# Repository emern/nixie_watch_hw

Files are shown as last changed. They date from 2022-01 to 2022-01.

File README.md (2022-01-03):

# nixie_watch_hw
Hardware for an IN-16 nixie tube based wristwatch/pocketwatch designed in KiCAD 5.1.3. This project contains PCB for both the watch main-board and Nixie tube holder designed to be mounted perpendicularly to allow the tubes to be visible from above. Watch main-board contains both STM8L based MCU alongside 9v-186v flyback boost converter to supply the large running voltages required by the nixie tubes. More information on the IN-16 nixie tube can be found [here](http://www.tube-tester.com/sites/nixie/data/in16.htm).

## PCBs

There are two induvidual PCBs needed to construct this wristwatch.

* Watch main-board (MCU, power supply, nixie GPIO driver, status LED, input switches)
* Nixie tube holder (Nixie tube socket x2)

## Features

Some features of this watch include:

* 9v battery based power supply
* 9v-186v nixie tube power supply based on flyback boost topology
* Wake button, slider switch to select between various sleep modes
* Status (mins/hours mode) LED indicator
* 2 nixie tube display
* 32mm radius
* [Firmware avaliable](https://github.com/emern/nixie_watch_fw)

## License

This project is licensed under the GPL-3.0 License.

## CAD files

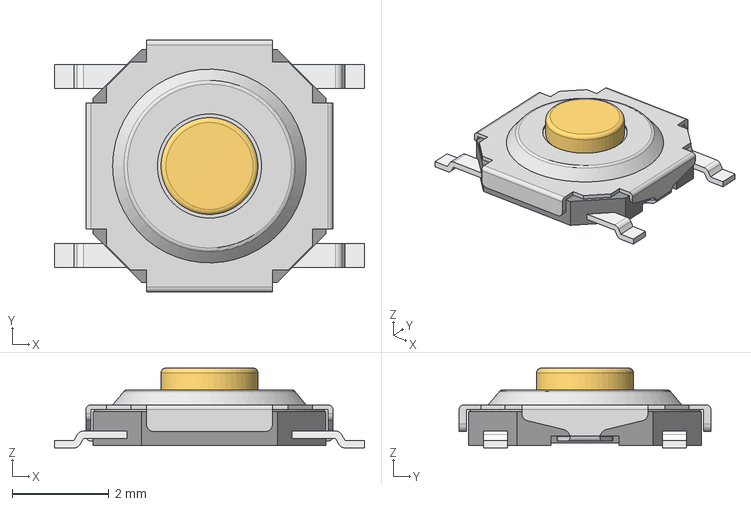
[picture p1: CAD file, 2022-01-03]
watch_v1/Switch_C&K_PTS526SK15SMTR2LFS/eec.models/C&K_-_PTS526SK15SMTR2LFS.step
6.40 x 5.20 x 1.65 mm

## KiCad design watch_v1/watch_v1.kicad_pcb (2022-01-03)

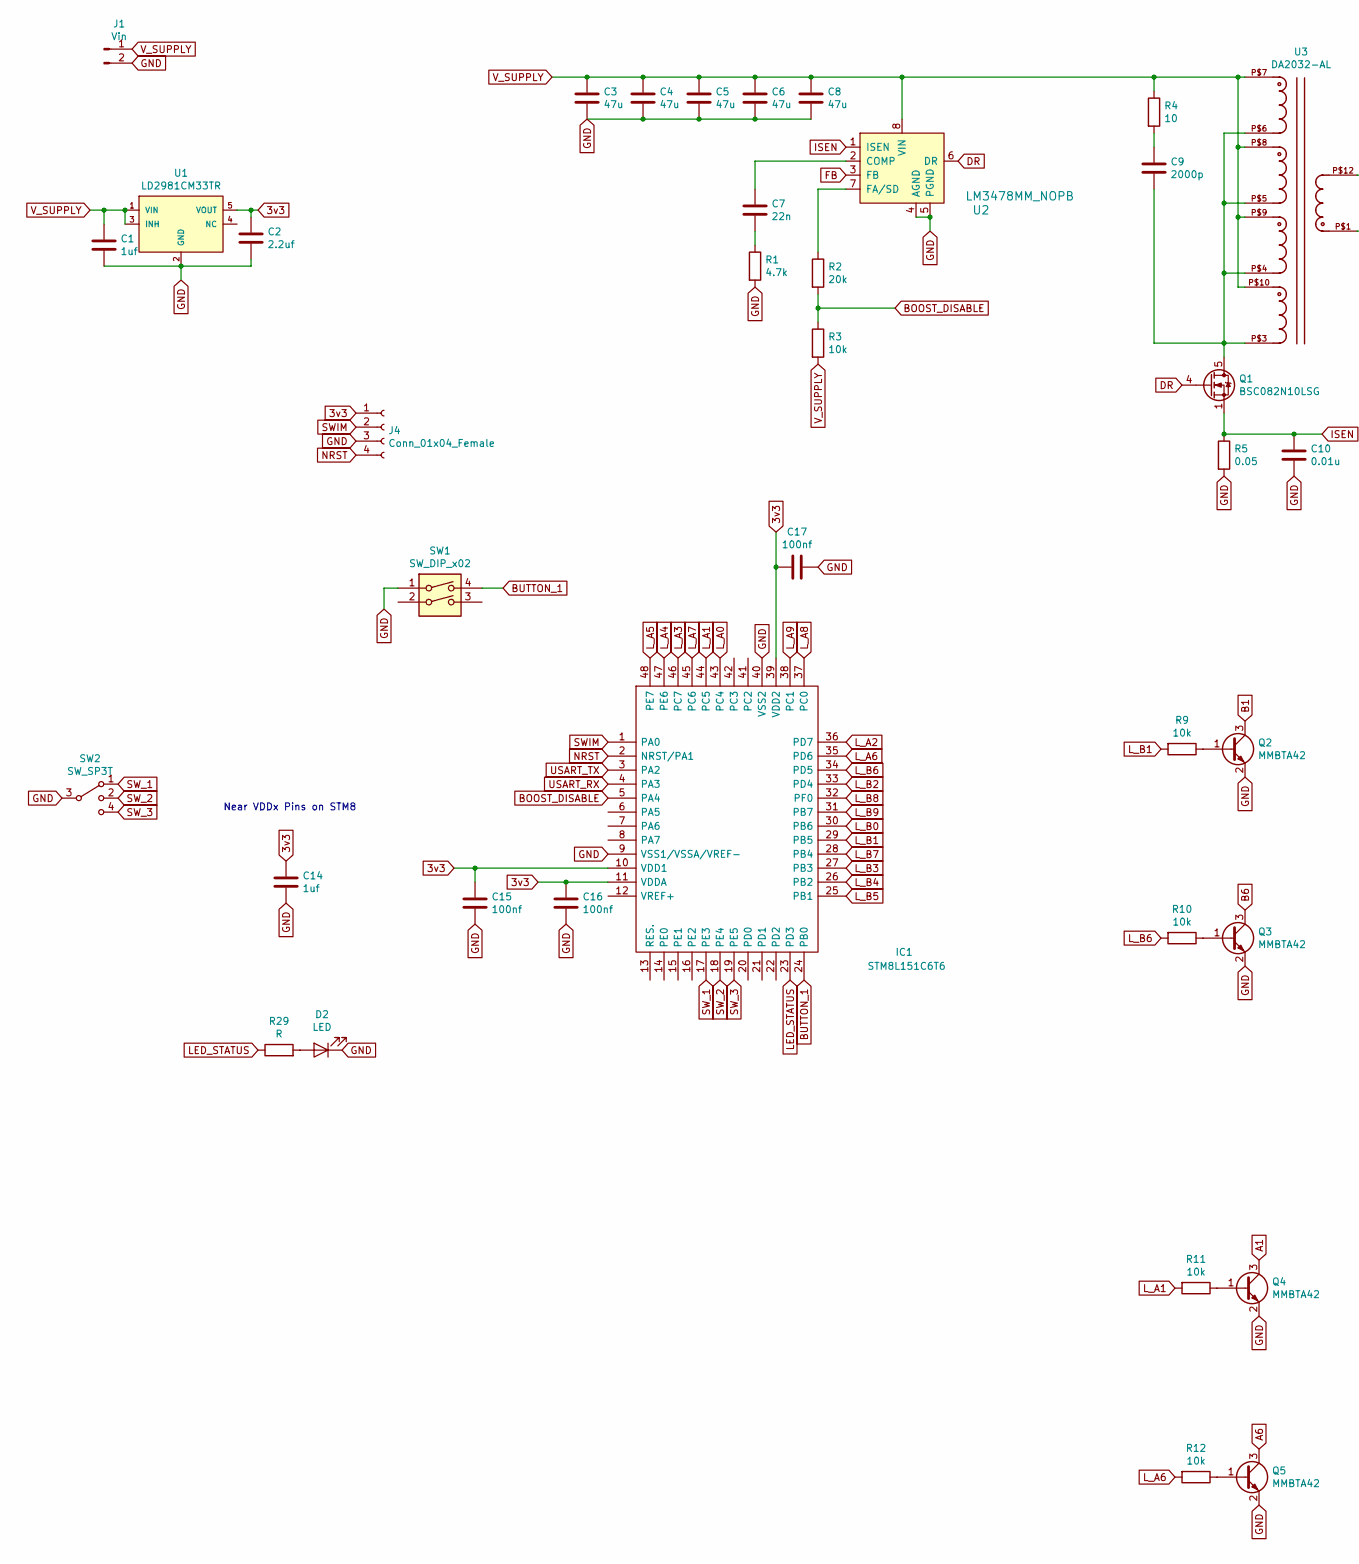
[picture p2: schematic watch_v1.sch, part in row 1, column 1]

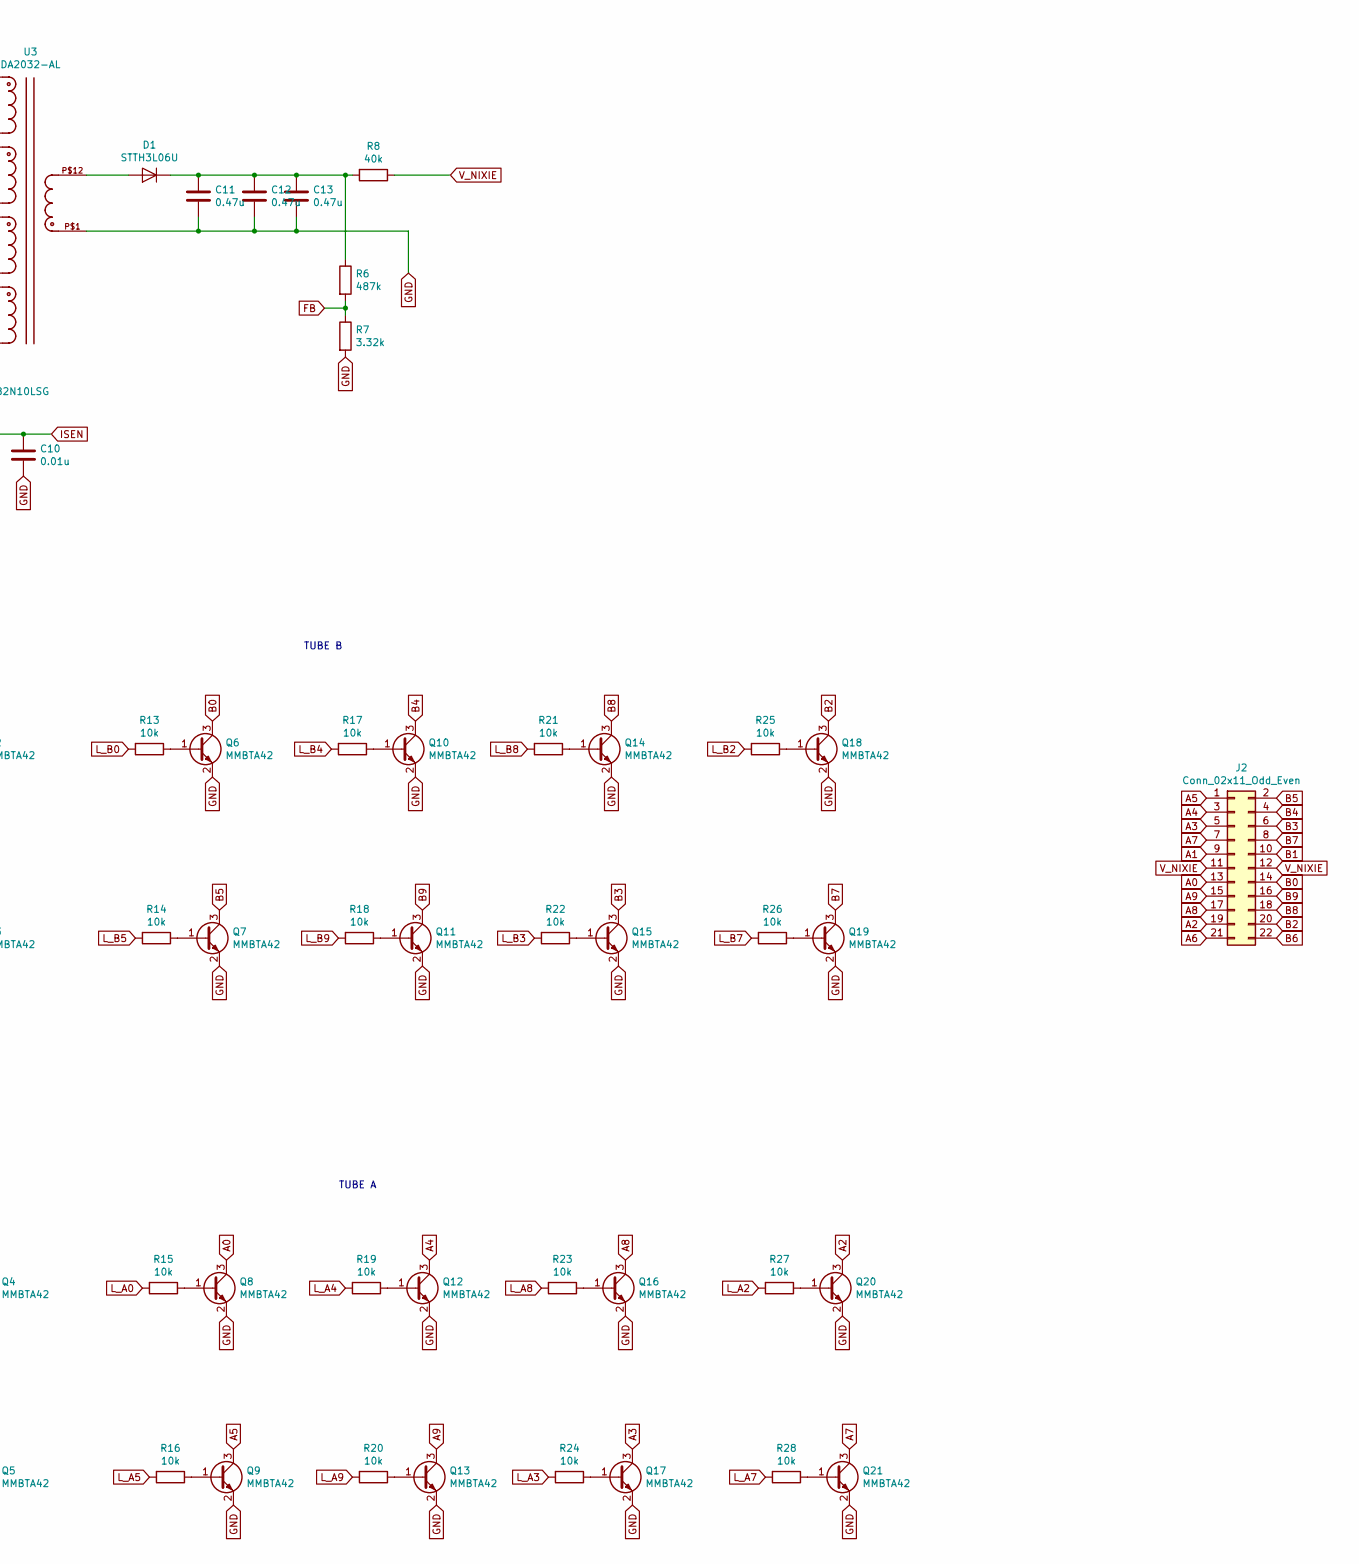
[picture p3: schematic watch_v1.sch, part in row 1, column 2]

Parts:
C1, C14: 1uf; C_1206_3216Metric
C2: 2.2uf; C_0805_2012Metric
C3, C4, C5, C6, C8: 47u; C_0805_2012Metric
C7: 22n; C_0402_1005Metric
C9: 2000p; C_0603_1608Metric
C10: 0.01u; C_0603_1608Metric
C11, C12, C13: 0.47u; C_1210_3225Metric
C15, C16, C17: 100nf; C_0805_2012Metric
D1: STTH3L06U; D_SMB
D2: LED; LED_0402_1005Metric
IC1: STM8L151C6T6; LQFP-48_7x7mm_P0.5mm; Manufacturer_Part_Number STM8L151C6T6; Mouser Part Number 511-STM8L151C6T6
J1: Vin; PinSocket_1x02_P2.54mm_Vertical
J2: Conn_02x11_Odd_Even; PinHeader_Nixie_1_37mm
J4: Conn_01x04_Female; PinHeader_1x04_P2.54mm_Vertical
Q1: BSC082N10LSG; TDSON-8-1
Q2, Q3, Q4, Q5, Q6, Q7, Q8, Q9, Q10, Q11, Q12, Q13, Q14, Q15, Q16, Q17, Q18, Q19, Q20, Q21: MMBTA42; SOT-23
R1: 4.7k; R_0805_2012Metric
R2: 20k; R_0603_1608Metric
R3: 10k; R_0603_1608Metric
R4: 10; R_0805_2012Metric
R5: 0.05; R_0402_1005Metric
R6: 487k; R_0805_2012Metric
R7: 3.32k; R_0603_1608Metric
R8: 40k; R_1206_3216Metric
R9, R10, R11, R12, R13, R14, R15, R16, R17, R18, R19, R20, R21, R22, R23, R24, R25, R26, R27, R28: 10k; R_0402_1005Metric
R29: R; R_1206_3216Metric
SW1: SW_DIP_x02; CK-PTS526SK15SMTR2LFS-0-0-MFG
SW2: SW_SP3T; SW_PCM13SMTR
U1: LD2981CM33TR; SOT-23-5
U2: LM3478MM_NOPB; SOIC-8_W3.9mm; MPN LM3478MM/NOPB; Digi-Key_PN LM3478MM/NOPBCT-ND
U3: DA2032-AL

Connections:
3v3: C2.1, C14.1, C15.1, C16.1, C17.2, IC1.10 (VDD1), IC1.11 (VDDA), IC1.39 (VDD2), J4.1, U1.5 (VOUT)
A0: J2.13, Q8.3 (C)
A1: J2.9, Q4.3 (C)
A2: J2.19, Q20.3 (C)
A3: J2.5, Q17.3 (C)
A4: J2.3, Q12.3 (C)
A5: J2.1, Q9.3 (C)
A6: J2.21, Q5.3 (C)
A7: J2.7, Q21.3 (C)
A8: J2.17, Q16.3 (C)
A9: J2.15, Q13.3 (C)
B0: J2.14, Q6.3 (C)
B1: J2.10, Q2.3 (C)
B2: J2.20, Q18.3 (C)
B3: J2.6, Q15.3 (C)
B4: J2.4, Q10.3 (C)
B5: J2.2, Q7.3 (C)
B6: J2.22, Q3.3 (C)
B7: J2.8, Q19.3 (C)
B8: J2.18, Q14.3 (C)
B9: J2.16, Q11.3 (C)
BOOST_DISABLE: IC1.5 (PA4), R2.2, R3.1
BUTTON_1: IC1.24 (PB0), SW1.4
DR: Q1.4 (G), U2.6 (DR)
FB: R6.2, R7.1, U2.3 (FB)
GND: C1.2, C2.2, C3.2, C4.2, C5.2, C6.2, C8.2, C10.2, C11.2, C12.2, C13.2, C14.2, C15.2, C16.2, C17.1, D2.1 (K), IC1.9 (VSS1/VSSA/VREF-), IC1.40 (VSS2), J1.2, J4.3, Q2.2 (E), Q3.2 (E), Q4.2 (E), Q5.2 (E), Q6.2 (E), Q7.2 (E), Q8.2 (E), Q9.2 (E), Q10.2 (E), Q11.2 (E), Q12.2 (E), Q13.2 (E), Q14.2 (E), Q15.2 (E), Q16.2 (E), Q17.2 (E), Q18.2 (E), Q19.2 (E), Q20.2 (E), Q21.2 (E), R1.2, R5.2, R7.2, SW1.1, SW2.3, U1.2 (GND), U2.4 (AGND), U2.5 (PGND), U3.P$1
ISEN: C10.1, Q1.1 (S), Q1.2 (S), Q1.3 (S), R5.1, U2.1 (ISEN)
LED_STATUS: IC1.23 (PD3), R29.1
L_A0: IC1.43 (PC4), R15.2
L_A1: IC1.44 (PC5), R11.2
L_A2: IC1.36 (PD7), R27.2
L_A3: IC1.46 (PC7), R24.2
L_A4: IC1.47 (PE6), R19.2
L_A5: IC1.48 (PE7), R16.2
L_A6: IC1.35 (PD6), R12.2
L_A7: IC1.45 (PC6), R28.2
L_A8: IC1.37 (PC0), R23.2
L_A9: IC1.38 (PC1), R20.2
L_B0: IC1.30 (PB6), R13.2
L_B1: IC1.29 (PB5), R9.2
L_B2: IC1.33 (PD4), R25.2
L_B3: IC1.27 (PB3), R22.2
L_B4: IC1.26 (PB2), R17.2
L_B5: IC1.25 (PB1), R14.2
L_B6: IC1.34 (PD5), R10.2
L_B7: IC1.28 (PB4), R26.2
L_B8: IC1.32 (PF0), R21.2
L_B9: IC1.31 (PB7), R18.2
NRST: IC1.2 (NRST/PA1), J4.4
unnamed: C7.1, U2.2 (COMP)
unnamed: C7.2, R1.1
unnamed: C9.1, R4.2
unnamed: C9.2, Q1.5 (D), U3.P$3, U3.P$4, U3.P$5, U3.P$6
unnamed: C11.1, C12.1, C13.1, D1.1 (K), R6.1, R8.2
unnamed: D1.2 (A), U3.P$12
unnamed: D2.2 (A), R29.2
unnamed: Q2.1 (B), R9.1
unnamed: Q3.1 (B), R10.1
unnamed: Q4.1 (B), R11.1
unnamed: Q5.1 (B), R12.1
unnamed: Q6.1 (B), R13.1
unnamed: Q7.1 (B), R14.1
unnamed: Q8.1 (B), R15.1
unnamed: Q9.1 (B), R16.1
unnamed: Q10.1 (B), R17.1
unnamed: Q11.1 (B), R18.1
unnamed: Q12.1 (B), R19.1
unnamed: Q13.1 (B), R20.1
unnamed: Q14.1 (B), R21.1
unnamed: Q15.1 (B), R22.1
unnamed: Q16.1 (B), R23.1
unnamed: Q17.1 (B), R24.1
unnamed: Q18.1 (B), R25.1
unnamed: Q19.1 (B), R26.1
unnamed: Q20.1 (B), R27.1
unnamed: Q21.1 (B), R28.1
unnamed: R2.1, U2.7 (FA/SD)
SWIM: IC1.1 (PA0), J4.2
SW_1: IC1.17 (PE3), SW2.1
SW_2: IC1.18 (PE4), SW2.2
SW_3: IC1.19 (PE5), SW2.4
USART_RX: IC1.4 (PA3)
USART_TX: IC1.3 (PA2)
V_NIXIE: J2.11, J2.12, R8.1
V_SUPPLY: C1.1, C3.1, C4.1, C5.1, C6.1, C8.1, J1.1, R3.2, R4.1, U1.1 (VIN), U1.3 (INH), U2.8 (VIN), U3.P$7, U3.P$8, U3.P$9, U3.P$10

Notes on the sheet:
Near VDDx Pins on STM8
TUBE B
TUBE A

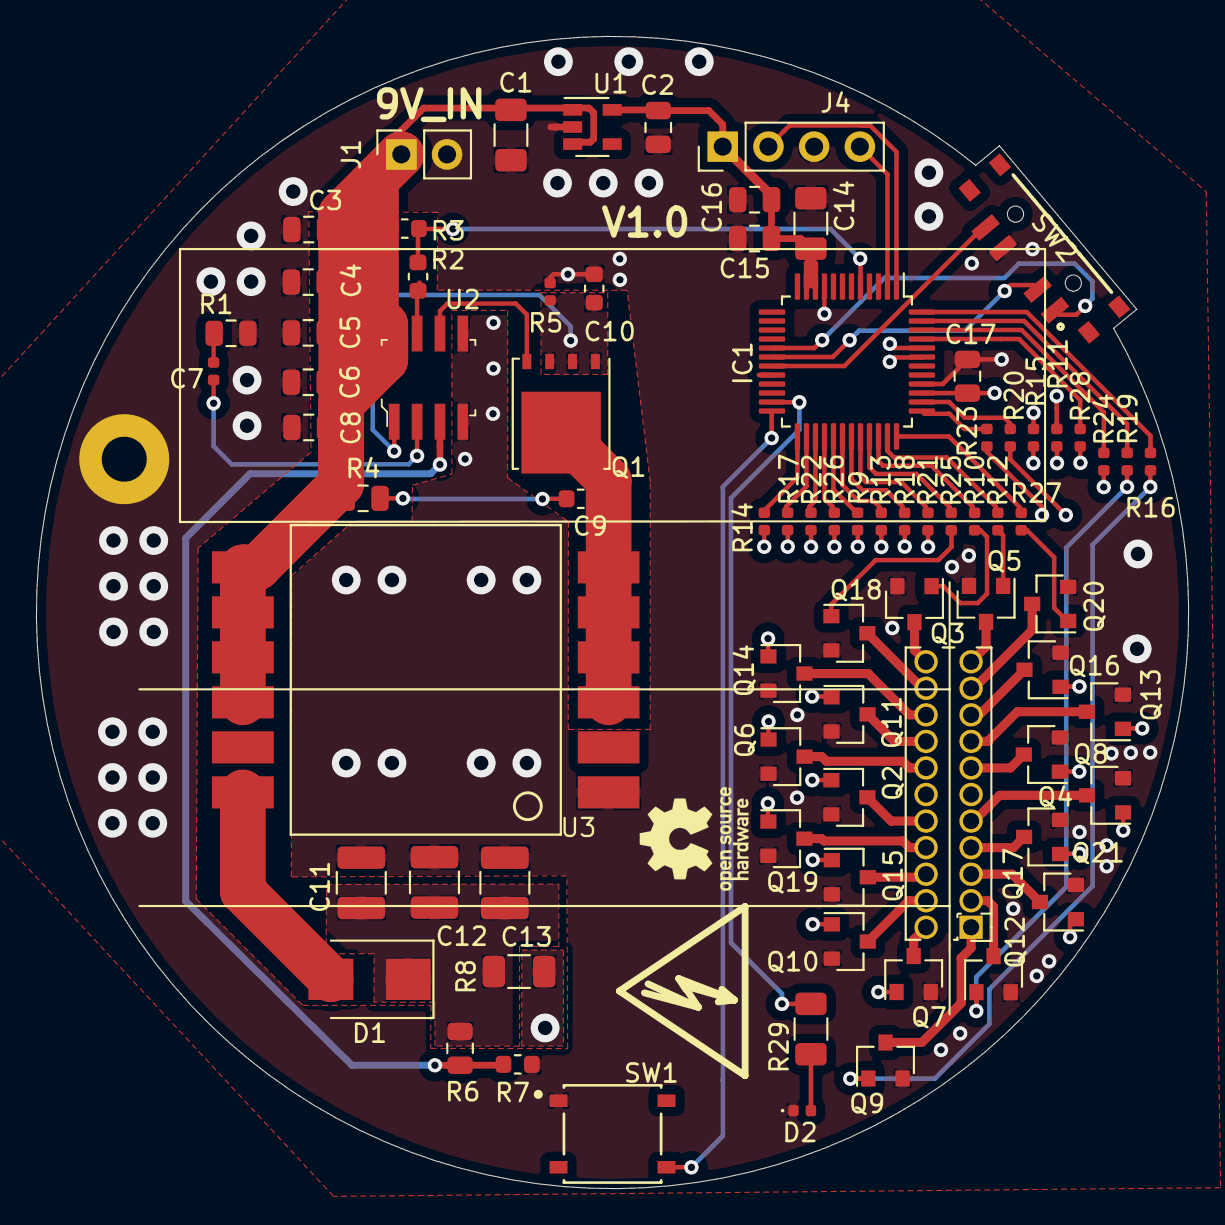
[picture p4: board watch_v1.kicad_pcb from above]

Board: 4 copper layers, 64.0 x 64.0 mm, 78 parts (0 on the bottom side), 83 nets.

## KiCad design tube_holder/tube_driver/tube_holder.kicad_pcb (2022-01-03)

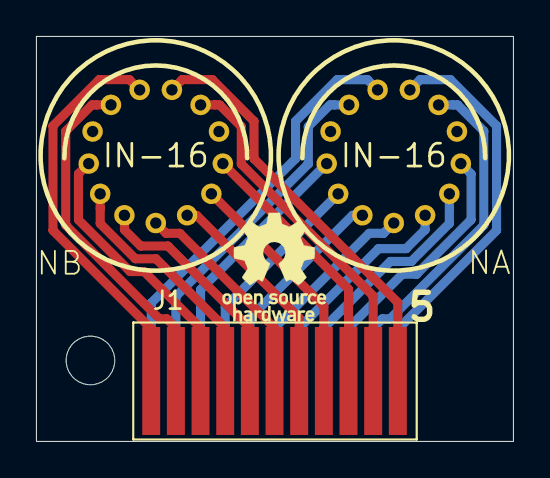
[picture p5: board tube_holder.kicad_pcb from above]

Board: 2 copper layers, 26.5 x 22.5 mm, 4 parts (1 on the bottom side), 22 nets.

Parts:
J1, J2: Conn_01x11_Female; smd_nixie_header_socket
NA: IN-16; nixies-us-IN-16
NB: IN-16; nixies-us-IN-16

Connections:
A0: J2.5, NA.0
A1: J2.7, NA.1
A2: J2.2, NA.2
A3: J2.9, NA.3
A4: J2.10, NA.4
A5: J2.11, NA.5
A6: J2.1, NA.6
A7: J2.8, NA.7
A8: J2.3, NA.8
A9: J2.4, NA.9
B0: J1.5, NB.0
B1: J1.7, NB.1
B2: J1.2, NB.2
B3: J1.9, NB.3
B4: J1.10, NB.4
B5: J1.11, NB.5
B6: J1.1, NB.6
B7: J1.8, NB.7
B8: J1.3, NB.8
B9: J1.4, NB.9
VA: J2.6, NA.A
VB: J1.6, NB.A

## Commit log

2022-01-03 adding hardware files
    [C&K_-_PTS526SK15SMTR2LFS.step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]
2022-01-03 clean up files
    [watch_1_27_pitch.kicad_pcb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]
2022-01-03 clean up tube holder files
    [tube_holder-B_Cu.gbr, tube_holder-B_Mask.gbr, tube_holder-B_SilkS.gbr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]
